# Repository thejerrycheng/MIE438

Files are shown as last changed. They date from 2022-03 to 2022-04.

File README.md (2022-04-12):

# MIE438_LED_cubic_console! 

This is an instruction of how to setup your own 8 by 8 by 8 LED game console. As there are tons of build-videos out there on YouTube. 

This report will only focus on the circuit design and the software aspect on how to light up the cube. Those two aspects were the consierably most challenging parts of the projects. 

In addition, it will walk through the two games created for the cube: Snake and Pong, two most classic console games of all time! (BUT in 3D!)

Lots of embedded system to be discovered. Let's dive into the lowest levels!

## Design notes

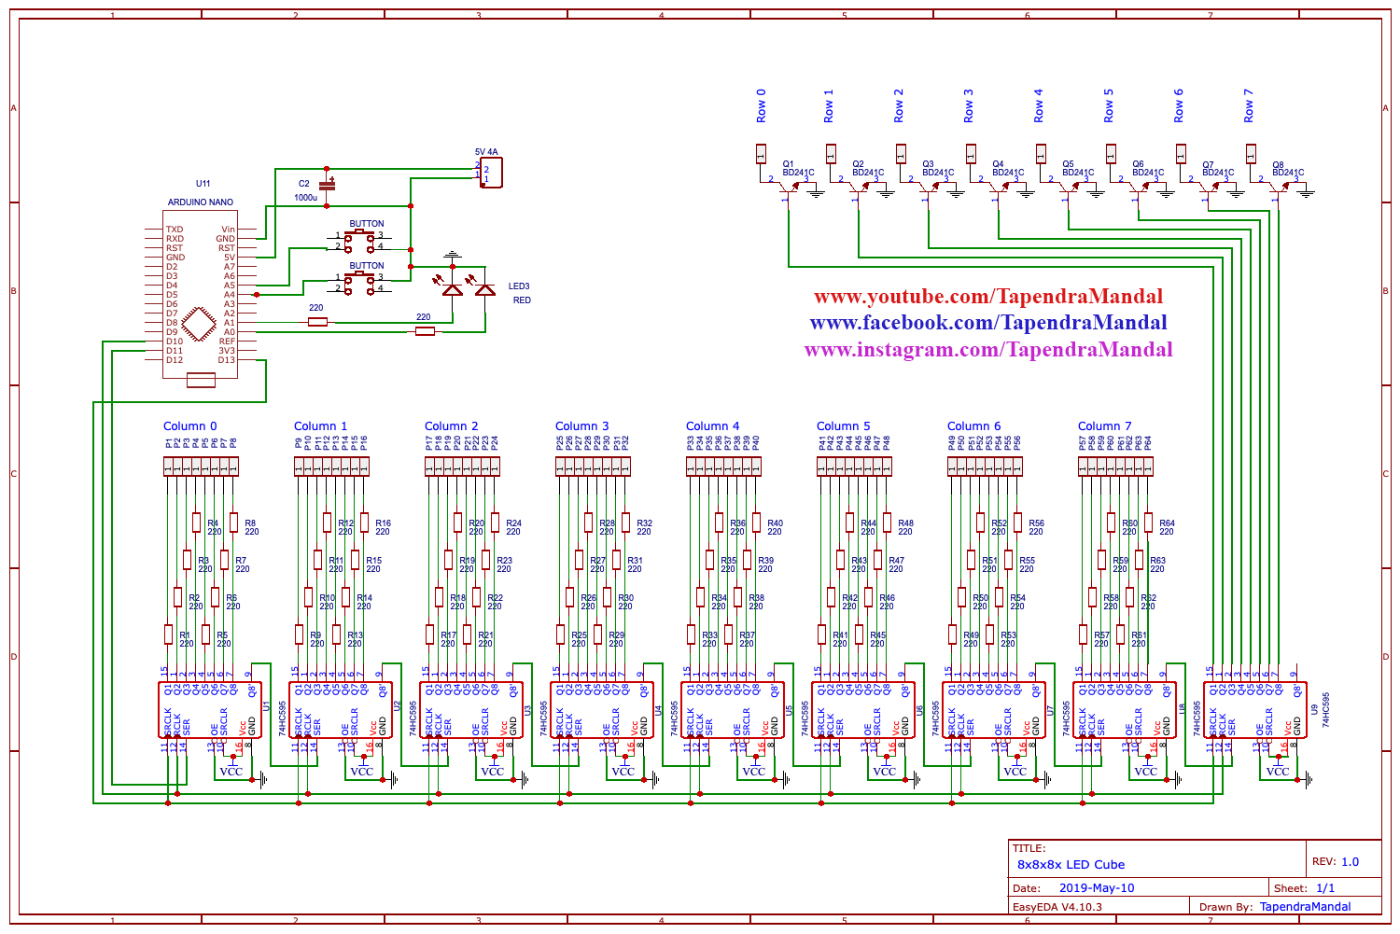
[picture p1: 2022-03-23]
8x8x8 LED Cube Circuit Diagram.jpg

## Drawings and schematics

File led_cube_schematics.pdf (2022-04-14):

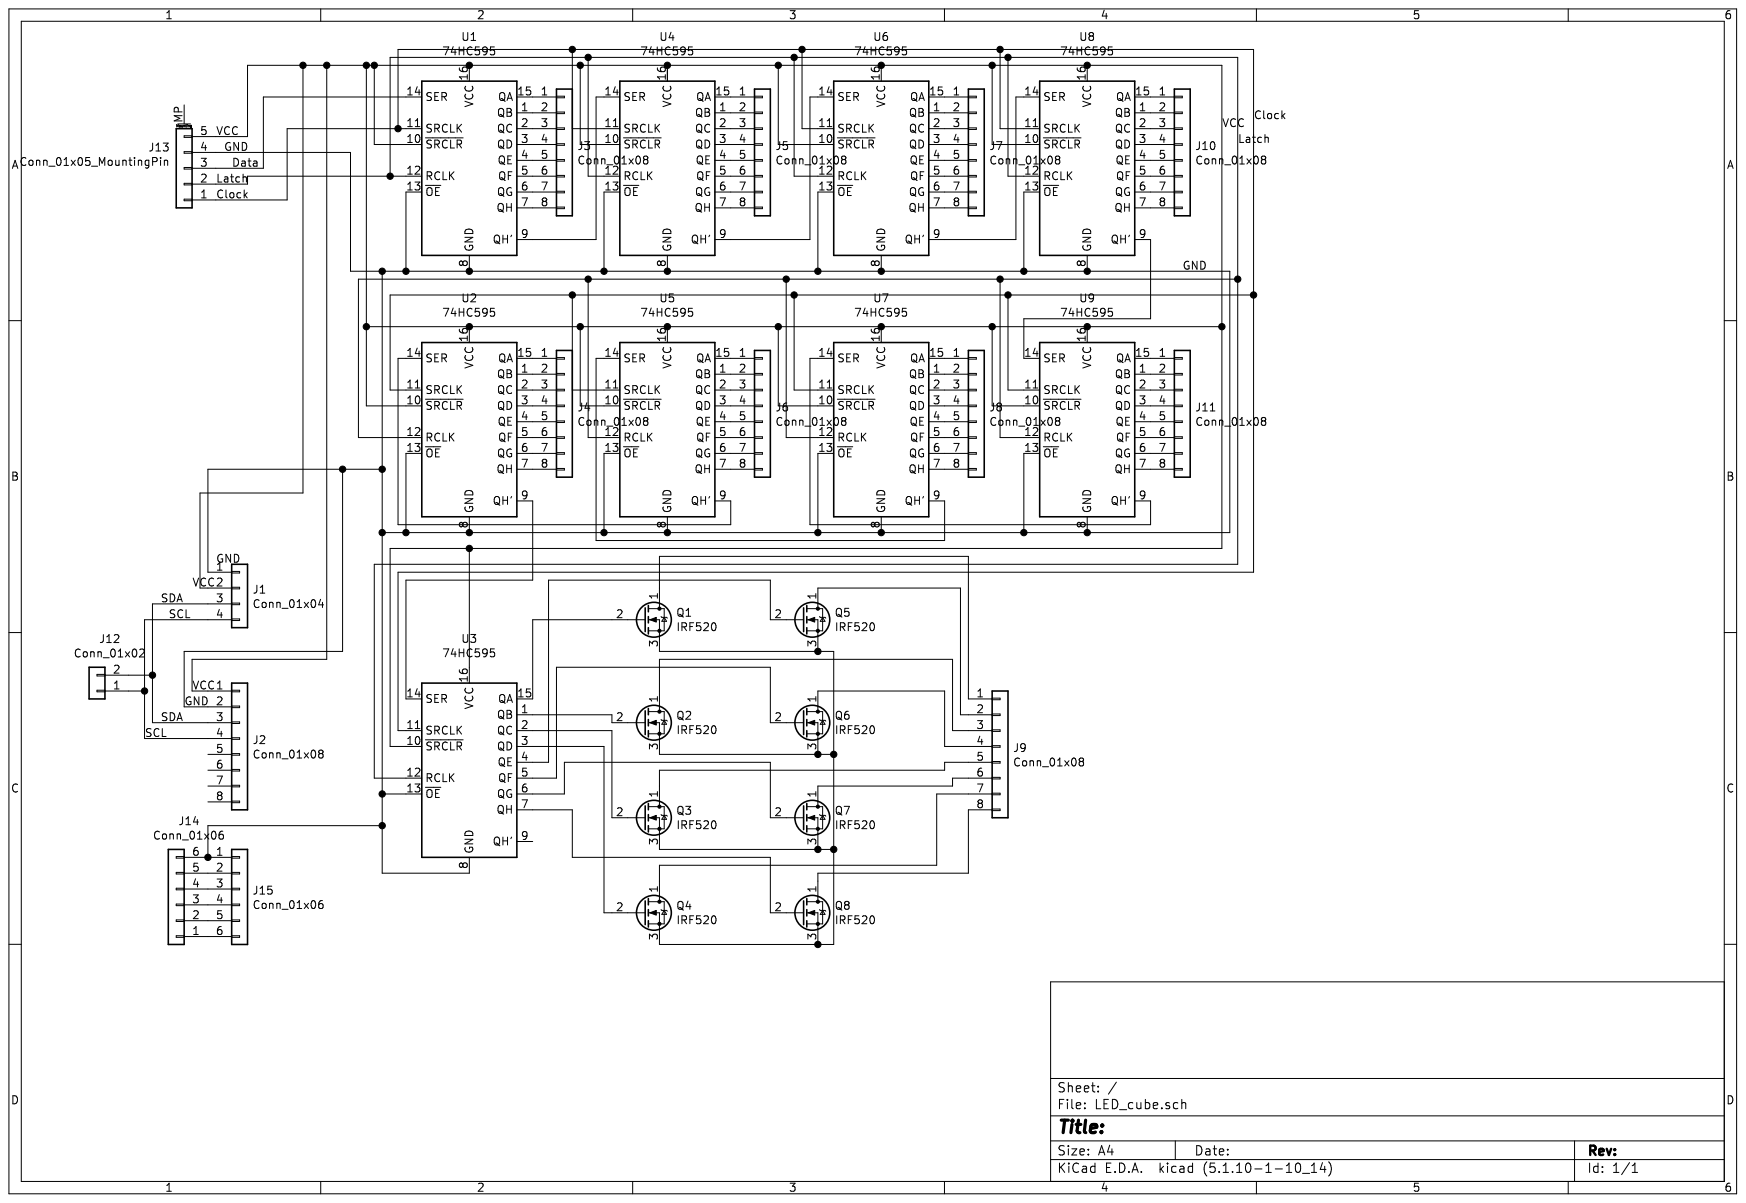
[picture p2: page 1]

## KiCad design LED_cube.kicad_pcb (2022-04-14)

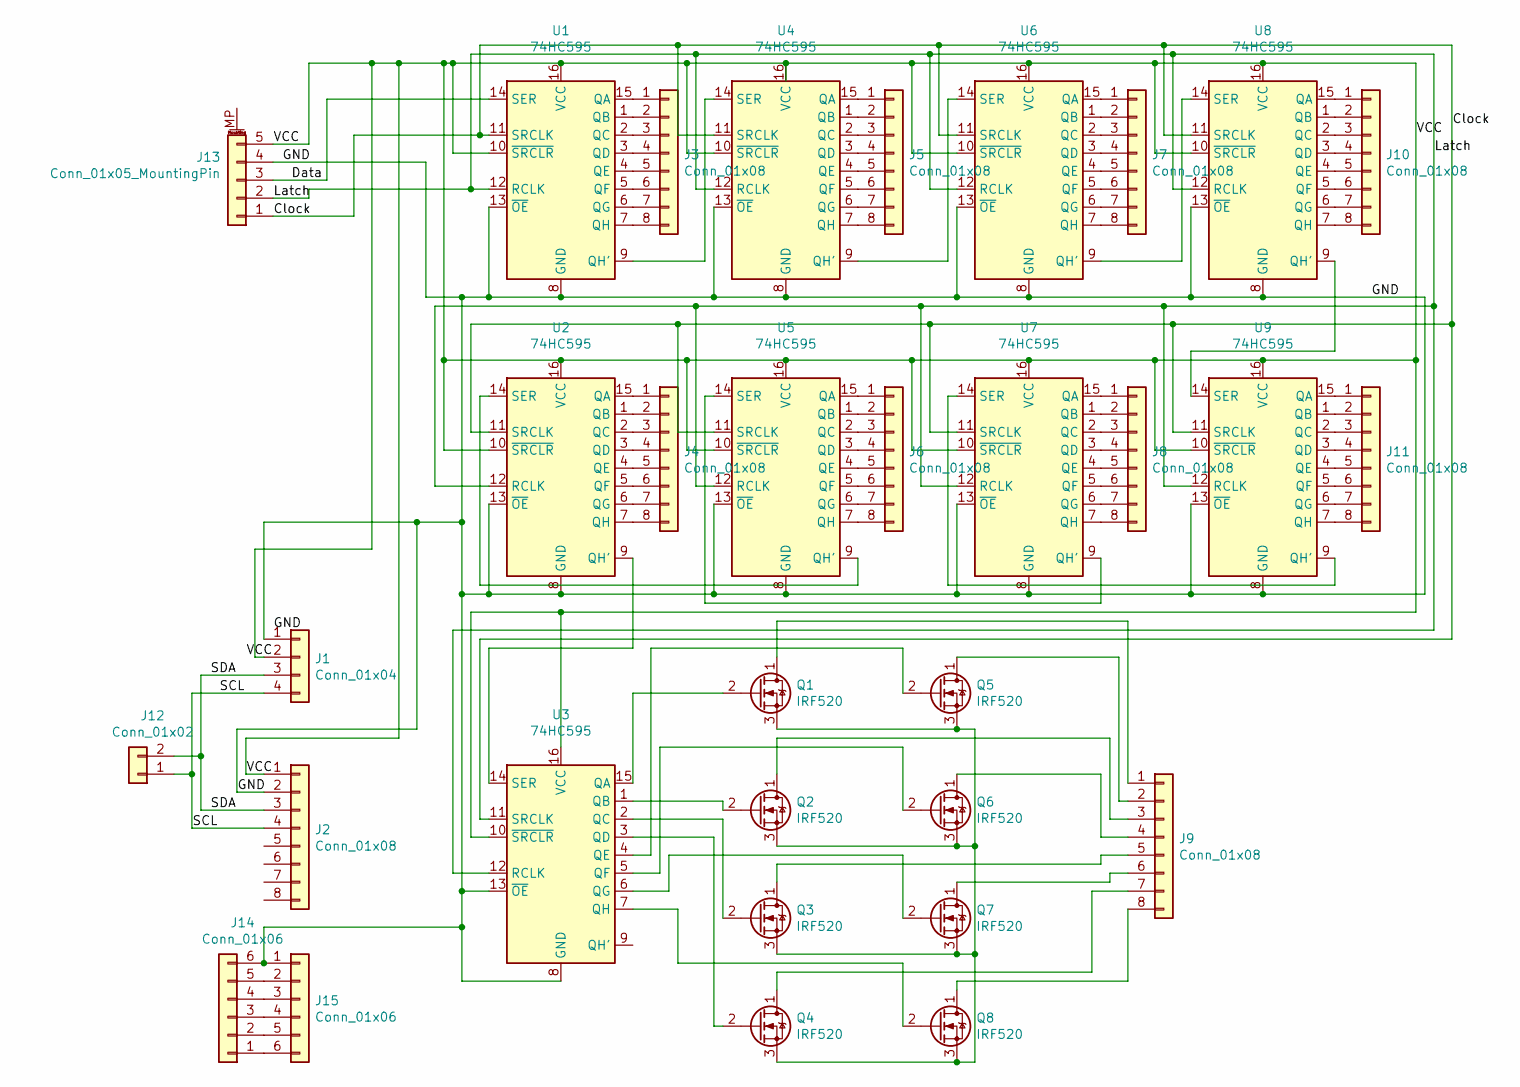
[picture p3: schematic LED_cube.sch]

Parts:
J1: Conn_01x04; PinSocket_1x04_P2.54mm_Vertical
J2, J3, J4, J5, J6, J7, J8, J9, J10, J11: Conn_01x08; PinSocket_1x08_P2.54mm_Vertical
J12: Conn_01x02; PinSocket_1x02_P2.54mm_Vertical
J13: Conn_01x05_MountingPin; PinSocket_1x05_P2.54mm_Vertical
J14, J15: Conn_01x06; PinSocket_1x06_P2.54mm_Vertical
Q1, Q2, Q4, Q7, Q8: IRF520; TO-262-3-1EP_Horizontal_TabDown
Q3: IRF520; DirectFET_MX
Q5, Q6: IRF520; TO-251-3-1EP_Horizontal_TabDown
U1, U2, U3, U4, U5, U6, U7, U8, U9: 74HC595; DIP-16_W7.62mm_Socket

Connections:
/Clock: J13.1, U1.11 (SRCLK), U2.11 (SRCLK), U3.11 (SRCLK), U4.11 (SRCLK), U5.11 (SRCLK), U6.11 (SRCLK), U7.11 (SRCLK), U8.11 (SRCLK), U9.11 (SRCLK)
/Data: J13.3, U1.14 (SER)
/GND: J1.1, J2.2, J13.4, J14.6, J15.1, U1.8 (GND), U1.13 (~OE), U2.8 (GND), U2.13 (~OE), U3.8 (GND), U3.13 (~OE), U4.8 (GND), U4.13 (~OE), U5.8 (GND), U5.13 (~OE), U6.8 (GND), U6.13 (~OE), U7.8 (GND), U7.13 (~OE), U8.8 (GND), U8.13 (~OE), U9.8 (GND), U9.13 (~OE)
/Latch: J13.2, U1.12 (RCLK), U2.12 (RCLK), U3.12 (RCLK), U4.12 (RCLK), U5.12 (RCLK), U6.12 (RCLK), U7.12 (RCLK), U8.12 (RCLK), U9.12 (RCLK)
/SCL: J1.4, J2.4, J12.1
/SDA: J1.3, J2.3, J12.2
/VCC: J1.2, J2.1, J13.5, U1.10 (~SRCLR), U1.16 (VCC), U2.10 (~SRCLR), U2.16 (VCC), U3.10 (~SRCLR), U3.16 (VCC), U4.10 (~SRCLR), U4.16 (VCC), U5.10 (~SRCLR), U5.16 (VCC), U6.10 (~SRCLR), U6.16 (VCC), U7.10 (~SRCLR), U7.16 (VCC), U8.10 (~SRCLR), U8.16 (VCC), U9.10 (~SRCLR), U9.16 (VCC)
unnamed: J3.1, U1.15 (QA)
unnamed: J3.2, U1.1 (QB)
unnamed: J3.3, U1.2 (QC)
unnamed: J3.4, U1.3 (QD)
unnamed: J3.5, U1.4 (QE)
unnamed: J3.6, U1.5 (QF)
unnamed: J3.7, U1.6 (QG)
unnamed: J3.8, U1.7 (QH)
unnamed: J4.1, U2.15 (QA)
unnamed: J4.2, U2.1 (QB)
unnamed: J4.3, U2.2 (QC)
unnamed: J4.4, U2.3 (QD)
unnamed: J4.5, U2.4 (QE)
unnamed: J4.6, U2.5 (QF)
unnamed: J4.7, U2.6 (QG)
unnamed: J4.8, U2.7 (QH)
unnamed: J5.1, U4.15 (QA)
unnamed: J5.2, U4.1 (QB)
unnamed: J5.3, U4.2 (QC)
unnamed: J5.4, U4.3 (QD)
unnamed: J5.5, U4.4 (QE)
unnamed: J5.6, U4.5 (QF)
unnamed: J5.7, U4.6 (QG)
unnamed: J5.8, U4.7 (QH)
unnamed: J6.1, U5.15 (QA)
unnamed: J6.2, U5.1 (QB)
unnamed: J6.3, U5.2 (QC)
unnamed: J6.4, U5.3 (QD)
unnamed: J6.5, U5.4 (QE)
unnamed: J6.6, U5.5 (QF)
unnamed: J6.7, U5.6 (QG)
unnamed: J6.8, U5.7 (QH)
unnamed: J7.1, U6.15 (QA)
unnamed: J7.2, U6.1 (QB)
unnamed: J7.3, U6.2 (QC)
unnamed: J7.4, U6.3 (QD)
unnamed: J7.5, U6.4 (QE)
unnamed: J7.6, U6.5 (QF)
unnamed: J7.7, U6.6 (QG)
unnamed: J7.8, U6.7 (QH)
unnamed: J8.1, U7.15 (QA)
unnamed: J8.2, U7.1 (QB)
unnamed: J8.3, U7.2 (QC)
unnamed: J8.4, U7.3 (QD)
unnamed: J8.5, U7.4 (QE)
unnamed: J8.6, U7.5 (QF)
unnamed: J8.7, U7.6 (QG)
unnamed: J8.8, U7.7 (QH)
unnamed: J9.1, Q1.1 (D)
unnamed: J9.2, Q5.1 (D)
unnamed: J9.3, Q2.1 (D)
unnamed: J9.4, Q6.1 (D)
unnamed: J9.5, Q3.1 (D)
unnamed: J9.6, Q7.1 (D)
unnamed: J9.7, Q4.1 (D)
unnamed: J9.8, Q8.1 (D)
unnamed: J10.1, U8.15 (QA)
unnamed: J10.2, U8.1 (QB)
unnamed: J10.3, U8.2 (QC)
unnamed: J10.4, U8.3 (QD)
unnamed: J10.5, U8.4 (QE)
unnamed: J10.6, U8.5 (QF)
unnamed: J10.7, U8.6 (QG)
unnamed: J10.8, U8.7 (QH)
unnamed: J11.1, U9.15 (QA)
unnamed: J11.2, U9.1 (QB)
unnamed: J11.3, U9.2 (QC)
unnamed: J11.4, U9.3 (QD)
unnamed: J11.5, U9.4 (QE)
unnamed: J11.6, U9.5 (QF)
unnamed: J11.7, U9.6 (QG)
unnamed: J11.8, U9.7 (QH)
unnamed: J14.1, J15.6
unnamed: J14.2, J15.5
unnamed: J14.3, J15.4
unnamed: J14.4, J15.3
unnamed: J14.5, J15.2
unnamed: Q1.2 (G), U3.15 (QA)
unnamed: Q1.3 (S), Q2.3 (S), Q3.3 (S), Q4.3 (S), Q5.3 (S), Q6.3 (S), Q7.3 (S), Q8.3 (S)
unnamed: Q2.2 (G), U3.1 (QB)
unnamed: Q3.2 (G), U3.2 (QC)
unnamed: Q4.2 (G), U3.3 (QD)
unnamed: Q5.2 (G), U3.4 (QE)
unnamed: Q6.2 (G), U3.5 (QF)
unnamed: Q7.2 (G), U3.6 (QG)
unnamed: Q8.2 (G), U3.7 (QH)
unnamed: U1.9 (QH'), U4.14 (SER)
unnamed: U2.9 (QH'), U3.14 (SER)
unnamed: U2.14 (SER), U5.9 (QH')
unnamed: U4.9 (QH'), U6.14 (SER)
unnamed: U5.14 (SER), U7.9 (QH')
unnamed: U6.9 (QH'), U8.14 (SER)
unnamed: U7.14 (SER), U9.9 (QH')
unnamed: U8.9 (QH'), U9.14 (SER)

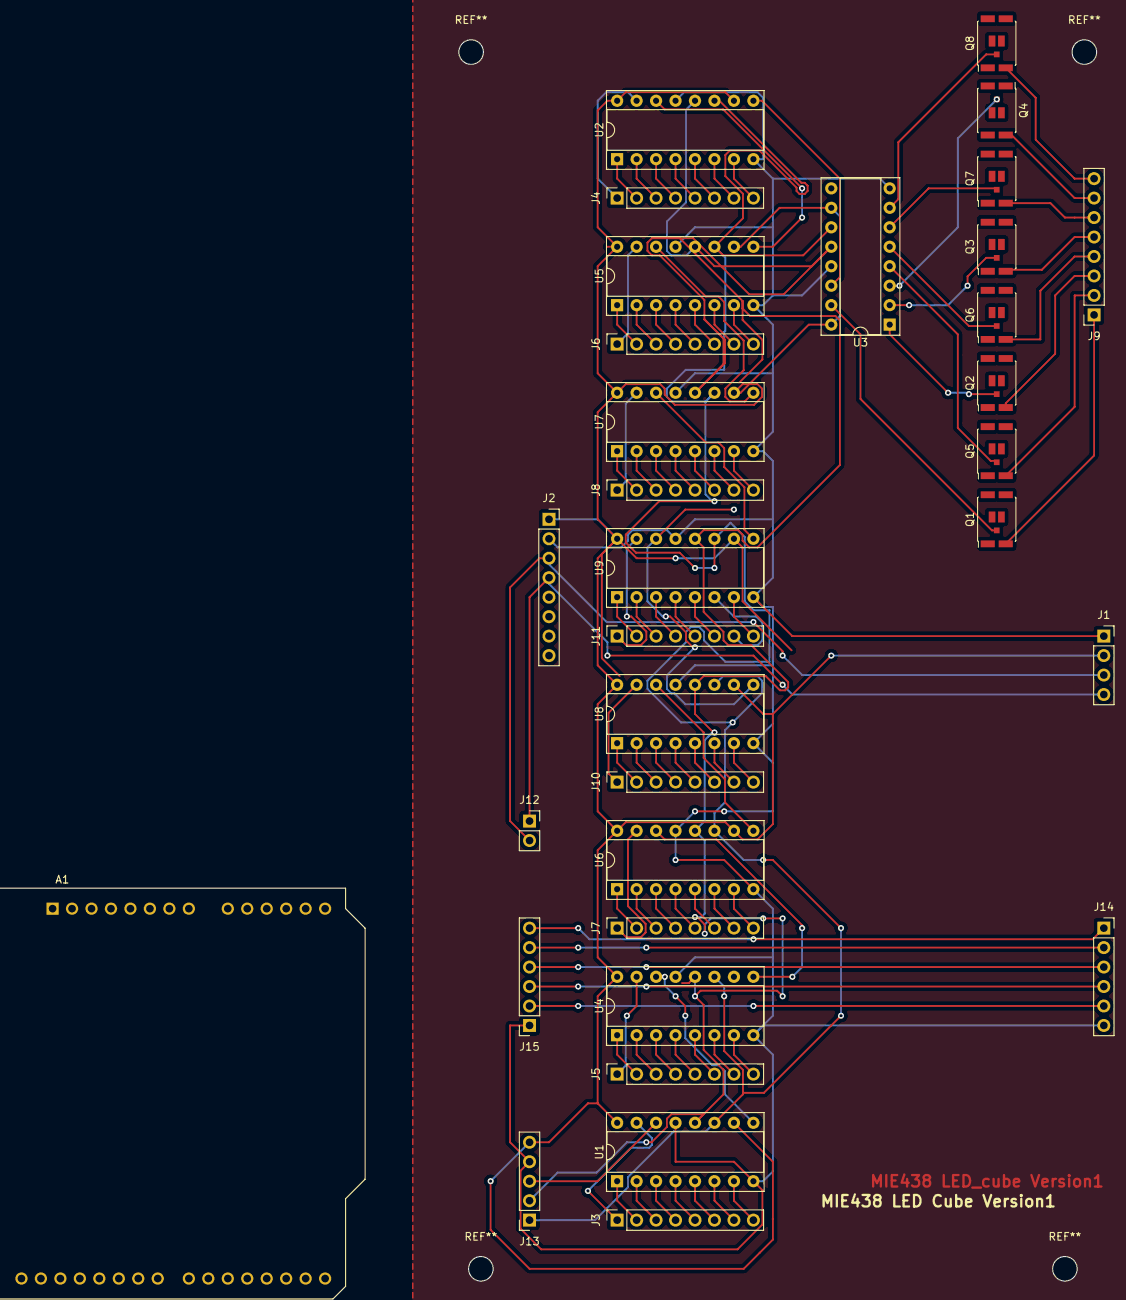
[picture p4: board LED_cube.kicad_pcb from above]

Board: 2 copper layers, 33 parts (0 on the bottom side), 101 nets.

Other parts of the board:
A1: Arduino_UNO_R2

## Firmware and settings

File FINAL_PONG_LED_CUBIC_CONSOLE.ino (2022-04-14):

#include <TimerOne.h>

#include <SPI.h>

#define XAXIS 0
#define YAXIS 1
#define ZAXIS 2

#define POS_X 0
#define NEG_X 1
#define POS_Z 2
#define NEG_Z 3
#define POS_Y 4
#define NEG_Y 5

#define BUTTON_PIN 8
#define RED_LED 5
#define GREEN_LED 7

#define TOTAL_EFFECTS 7
#define RAIN 0
#define PLANE_BOING 1
#define SEND_VOXELS 2
#define WOOP_WOOP 3
#define CUBE_JUMP 4
#define GLOW 5
#define TEXT 6
//#define LIT 7

#define RAIN_TIME 260
#define PLANE_BOING_TIME 220
#define SEND_VOXELS_TIME 140
#define WOOP_WOOP_TIME 350
#define CUBE_JUMP_TIME 200
#define GLOW_TIME 8
#define TEXT_TIME 300
#define CLOCK_TIME 500

uint8_t characters[10][8] = {
  {0x3C, 0x42, 0x42, 0x42, 0x42, 0x42, 0x42, 0x3C}, //0
  {0x10, 0x18, 0x14, 0x10, 0x10, 0x10, 0x10, 0x3C}, //1
  {0x3C, 0x42, 0x40, 0x40, 0x3C, 0x02, 0x02, 0x7E}, //2
  {0x3C, 0x40, 0x40, 0x3C, 0x40, 0x40, 0x42, 0x3C}, //3
  {0x22, 0x22, 0x22, 0x22, 0x7E, 0x20, 0x20, 0x20}, //4
  {0x7E, 0x02, 0x02, 0x3E, 0x40, 0x40, 0x42, 0x3C}, //5
  {0x3C, 0x02, 0x02, 0x3E, 0x42, 0x42, 0x42, 0x3C}, //6
  {0x3C, 0x40, 0x40, 0x40, 0x40, 0x40, 0x40, 0x40}, //7
  {0x3C, 0x42, 0x42, 0x3C, 0x42, 0x42, 0x42, 0x3C}, //8
  {0x3C, 0x42, 0x42, 0x42, 0x3C, 0x40, 0x40, 0x3C}, //9
};

uint8_t cube[8][8];
uint8_t currentEffect;
uint16_t timer;
uint64_t randomTimer;
bool loading;

int slaveSelectPin = 52;

int refresh_time = 0.1;
int layer_time = 0.01;

///////////////////////////////// global function to set the state of a voxel /////////////////////////////////
void writeVoxel(uint8_t x, uint8_t y, uint8_t z, bool state) {
  if (state == 0) {
    clearVoxel(x, y, z);
  }
  else {
    setVoxel(x, y, z);
  }
}

///////////////////////////////// set a voxel /////////////////////////////////
void setVoxel(uint8_t x, uint8_t y, uint8_t z) {
  cube[7 - y][7 - z] |= (0x01 << x);
}
///////////////////////////////// clear a voxel /////////////////////////////////
void clearVoxel(uint8_t x, uint8_t y, uint8_t z) {
  cube[y][z] &= ~(1 << x);
}
///////////////////////////////// flip a voxel /////////////////////////////////
void flipVoxel(uint8_t x, uint8_t y, uint8_t z) {
  cube[7 - y][7 - z] ^= (0x01 << x);
}
///////////////////////////////// get the state of the voxel /////////////////////////////////
bool getVoxel(uint8_t x, uint8_t y, uint8_t z) {
  return (cube[7 - y][7 - z] & (0x01 << x)) == (0x01 << x);
}

///////////////////////////////// set a plane to be lit up/////////////////////////////////
void setPlane(uint8_t axis, uint8_t i) {
  for (uint8_t j = 0; j < 8; j++) {
    for (uint8_t k = 0; k < 8; k++) {
      if (axis == XAXIS) {
        setVoxel(i, j, k);
      } else if (axis == YAXIS) {
        setVoxel(j, i, k);
      } else if (axis == ZAXIS) {
        setVoxel(j, k, i);
      }
    }
  }
}

///////////////////////////////// shift a plane to the direction given; dir can be: POS_X; POS_Y; POS_Z; NEG_X; NEG_Y; NEG_Z /////////////////////////////////
void shift(uint8_t dir) {

  if (dir == POS_X) {
    for (uint8_t y = 0; y < 8; y++) {
      for (uint8_t z = 0; z < 8; z++) {
        cube[y][z] = cube[y][z] << 1;
      }
    }
  } else if (dir == NEG_X) {
    for (uint8_t y = 0; y < 8; y++) {
      for (uint8_t z = 0; z < 8; z++) {
        cube[y][z] = cube[y][z] >> 1;
      }
    }
  } else if (dir == POS_Y) {
    for (uint8_t y = 1; y < 8; y++) {
      for (uint8_t z = 0; z < 8; z++) {
        cube[y - 1][z] = cube[y][z];
      }
    }
    for (uint8_t i = 0; i < 8; i++) {
      cube[7][i] = 0;
    }
  } else if (dir == NEG_Y) {
    for (uint8_t y = 7; y > 0; y--) {
      for (uint8_t z = 0; z < 8; z++) {
        cube[y][z] = cube[y - 1][z];
      }
    }
    for (uint8_t i = 0; i < 8; i++) {
      cube[0][i] = 0;
    }
  } else if (dir == POS_Z) {
    for (uint8_t y = 0; y < 8; y++) {
      for (uint8_t z = 1; z < 8; z++) {
        cube[y][z - 1] = cube[y][z];
      }
    }
    for (uint8_t i = 0; i < 8; i++) {
      cube[i][7] = 0;
    }
  } else if (dir == NEG_Z) {
    for (uint8_t y = 0; y < 8; y++) {
      for (uint8_t z = 7; z > 0; z--) {
        cube[y][z] = cube[y][z - 1];
      }
    }
    for (uint8_t i = 0; i < 8; i++) {
      cube[i][0] = 0;
    }
  }
}

///////////////////////////////// Draw a hallow cube /////////////////////////////////
void drawCube(uint8_t x, uint8_t y, uint8_t z, uint8_t s) {
  for (uint8_t i = 0; i < s; i++) {
    setVoxel(x, y + i, z);
    setVoxel(x + i, y, z);
    setVoxel(x, y, z + i);
    setVoxel(x + s - 1, y + i, z + s - 1);
    setVoxel(x + i, y + s - 1, z + s - 1);
    setVoxel(x + s - 1, y + s - 1, z + i);
    setVoxel(x + s - 1, y + i, z);
    setVoxel(x, y + i, z + s - 1);
    setVoxel(x + i, y + s - 1, z);
    setVoxel(x + i, y, z + s - 1);
    setVoxel(x + s - 1, y, z + i);
    setVoxel(x, y + s - 1, z + i);
  }
}
///////////////////////////////// set the buffer to ON for the entire cube /////////////////////////////////
void lightCube() {
  for (uint8_t i = 0; i < 8; i++) {
    for (uint8_t j = 0; j < 8; j++) {
      cube[i][j] = 0xFF;
    }
  }
}

///////////////////////////////// clear up all the buffer to OFF for enture cube /////////////////////////////////
void clearCube() {
  for (uint8_t i = 0; i < 8; i++) {
    for (uint8_t j = 0; j < 8; j++) {
      cube[i][j] = 0;
    }
  }
}


///////////////////////////////// Send the buffer data to the LED Cube! equvlent to display.display() function from the OLED display  /////////////////////////////////
//void renderCube() {
//  for (uint8_t i = 0; i < 8; i++) {
//    digitalWrite(slaveSelectPin, LOW);
//    SPI.transfer(0x01 << i);
//    //   SPI.transfer(0xFF);
//    for (uint8_t j = 0; j < 8; j++) {
//      SPI.transfer(cube[i][j]);
//      //SPI.transfer(0x11);
//      //delay(layer_time);
//    }
//    digitalWrite(slaveSelectPin, HIGH);
//  }
//  //delay(layer_time * 5);
//  for (uint8_t k = 0; k < 8; k++) {
//    digitalWrite(slaveSelectPin, LOW);
//    SPI.transfer(0x01 << k);
//    //    SPI.transfer(0xFF);
//    for (uint8_t j = 0; j < 8; j++) {
//      //      SPI.transfer(cube[k][j]);
//      SPI.transfer(0x00);
//    }
//    digitalWrite(slaveSelectPin, HIGH);
//  }
//  //delay(refresh_time);
//}



void renderCube() {
  for (uint8_t i = 0; i < 8; i++) {
    digitalWrite(SS, LOW);

    SPI.transfer(0x01 << i);
    for (uint8_t j = 0; j < 8; j++) {
      SPI.transfer(cube[i][j]);
    }
    digitalWrite(SS, HIGH);
  }
}

///////////////////////////////////////////////////////////////////////////
///////////////////////////////// Effects /////////////////////////////////
///////////////////////////////////////////////////////////////////////////


///////////////////////////////// Rain Effects /////////////////////////////////
void rain() {
  if (loading) {
    clearCube();
    loading = false;
  }
  timer++;
  if (timer > RAIN_TIME) {
    timer = 0;
    shift(NEG_Y);
    uint8_t numDrops = random(0, 5);
    for (uint8_t i = 0; i < numDrops; i++) {
      setVoxel(random(0, 8), 7, random(0, 8));
    }
  }
}
///////////////////////////////// Plane Boing Effects /////////////////////////////////

uint8_t planePosition = 0;
uint8_t planeDirection = 0;
bool looped = false;


void planeBoing() {
  if (loading) {
    clearCube();
    uint8_t axis = random(0, 3);
    planePosition = random(0, 2) * 7;
    setPlane(axis, planePosition);
    if (axis == XAXIS) {
      if (planePosition == 0) {
        planeDirection = POS_X;
      } else {
        planeDirection = NEG_X;
      }
    } else if (axis == YAXIS) {
      if (planePosition == 0) {
        planeDirection = POS_Y;
      } else {
        planeDirection = NEG_Y;
      }
    } else if (axis == ZAXIS) {
      if (planePosition == 0) {
        planeDirection = POS_Z;
      } else {
        planeDirection = NEG_Z;
      }
    }
    timer = 0;
    looped = false;
    loading = false;
  }

  timer++;
  if (timer > PLANE_BOING_TIME) {
    timer = 0;
    shift(planeDirection);
    if (planeDirection % 2 == 0) {
      planePosition++;
      if (planePosition == 7) {
        if (looped) {
          loading = true;
        } else {
          planeDirection++;
          looped = true;
        }
      }
    } else {
      planePosition--;
      if (planePosition == 0) {
        if (looped) {
          loading = true;
        } else {
          planeDirection--;
          looped = true;
        }
      }
    }
  }
}


///////////////////////////////// Send Voxel Effects /////////////////////////////////
uint8_t selX = 0;
uint8_t selY = 0;
uint8_t selZ = 0;
uint8_t sendDirection = 0;
bool sending = false;

void sendVoxels() {
  if (loading) {
    clearCube();
    for (uint8_t x = 0; x < 8; x++) {
      for (uint8_t z = 0; z < 8; z++) {
        setVoxel(x, random(0, 2) * 7, z);
      }
    }
    loading = false;
  }

  timer++;
  if (timer > SEND_VOXELS_TIME) {
    timer = 0;
    if (!sending) {
      selX = random(0, 8);
      selZ = random(0, 8);
      if (getVoxel(selX, 0, selZ)) {
        selY = 0;
        sendDirection = POS_Y;
      } else if (getVoxel(selX, 7, selZ)) {
        selY = 7;
        sendDirection = NEG_Y;
      }
      sending = true;
    } else {
      if (sendDirection == POS_Y) {
        selY++;
        setVoxel(selX, selY, selZ);
        clearVoxel(selX, selY - 1, selZ);
        if (selY == 7) {
          sending = false;
        }
      } else {
        selY--;
        setVoxel(selX, selY, selZ);
        clearVoxel(selX, selY + 1, selZ);
        if (selY == 0) {
          sending = false;
        }
      }
    }
  }
}




///////////////////////////////// Woop woop Effects /////////////////////////////////
uint8_t cubeSize = 0;
bool cubeExpanding = true;

void woopWoop() {
  if (loading) {
    clearCube();
    cubeSize = 2;
    cubeExpanding = true;
    loading = false;
  }

  timer++;
  if (timer > WOOP_WOOP_TIME) {
    timer = 0;
    if (cubeExpanding) {
      cubeSize += 2;
      if (cubeSize == 8) {
        cubeExpanding = false;
      }
    } else {
      cubeSize -= 2;
      if (cubeSize == 2) {
        cubeExpanding = true;
      }
    }
    clearCube();
    drawCube(4 - cubeSize / 2, 4 - cubeSize / 2, 4 - cubeSize / 2, cubeSize);
  }
}

///////////////////////////////// Cube Jump Effects /////////////////////////////////

uint8_t xPos;
uint8_t yPos;
uint8_t zPos;

void cubeJump() {
  if (loading) {
    clearCube();
    xPos = random(0, 2) * 7;
    yPos = random(0, 2) * 7;
    zPos = random(0, 2) * 7;
    cubeSize = 8;
    cubeExpanding = false;
    loading = false;
  }

  timer++;
  if (timer > CUBE_JUMP_TIME) {
    timer = 0;
    clearCube();
    if (xPos == 0 && yPos == 0 && zPos == 0) {
      drawCube(xPos, yPos, zPos, cubeSize);
    } else if (xPos == 7 && yPos == 7 && zPos == 7) {
      drawCube(xPos + 1 - cubeSize, yPos + 1 - cubeSize, zPos + 1 - cubeSize, cubeSize);
    } else if (xPos == 7 && yPos == 0 && zPos == 0) {
      drawCube(xPos + 1 - cubeSize, yPos, zPos, cubeSize);
    } else if (xPos == 0 && yPos == 7 && zPos == 0) {
      drawCube(xPos, yPos + 1 - cubeSize, zPos, cubeSize);
    } else if (xPos == 0 && yPos == 0 && zPos == 7) {
      drawCube(xPos, yPos, zPos + 1 - cubeSize, cubeSize);
    } else if (xPos == 7 && yPos == 7 && zPos == 0) {
      drawCube(xPos + 1 - cubeSize, yPos + 1 - cubeSize, zPos, cubeSize);
    } else if (xPos == 0 && yPos == 7 && zPos == 7) {
      drawCube(xPos, yPos + 1 - cubeSize, zPos + 1 - cubeSize, cubeSize);
    } else if (xPos == 7 && yPos == 0 && zPos == 7) {
      drawCube(xPos + 1 - cubeSize, yPos, zPos + 1 - cubeSize, cubeSize);
    }
    if (cubeExpanding) {
      cubeSize++;
      if (cubeSize == 8) {
        cubeExpanding = false;
        xPos = random(0, 2) * 7;
        yPos = random(0, 2) * 7;
        zPos = random(0, 2) * 7;
      }
    } else {
      cubeSize--;
      if (cubeSize == 1) {
        cubeExpanding = true;
      }
    }
  }
}


///////////////////////////////// Glowing Effects /////////////////////////////////

bool glowing;
uint16_t glowCount = 0;

void glow() {
  if (loading) {
    clearCube();
    glowCount = 0;
    glowing = true;
    loading = false;
  }

  timer++;
  if (timer > GLOW_TIME) {
    timer = 0;
    if (glowing) {
      if (glowCount < 448) {
        do {
          selX = random(0, 8);
          selY = random(0, 8);
          selZ = random(0, 8);
        } while (getVoxel(selX, selY, selZ));
        setVoxel(selX, selY, selZ);
        glowCount++;
      } else if (glowCount < 512) {
        lightCube();
        glowCount++;
      } else {
        glowing = false;
        glowCount = 0;
      }
    } else {
      if (glowCount < 448) {
        do {
          selX = random(0, 8);
          selY = random(0, 8);
          selZ = random(0, 8);
        } while (!getVoxel(selX, selY, selZ));
        clearVoxel(selX, selY, selZ);
        glowCount++;
      } else {
        clearCube();
        glowing = true;
        glowCount = 0;
      }
    }
  }
}


///////////////////////////////// Display Numbers from 0-9 Effects /////////////////////////////////

uint8_t charCounter = 0;
uint8_t charPosition = 0;

void text(char string[], uint8_t len) {
  if (loading) {
    clearCube();
    charPosition = -1;
    charCounter = 0;
    loading = false;
  }


  shift(NEG_Z);
  charPosition++;

  if (charPosition == 7) {
    charCounter++;
    if (charCounter > len - 1) {
      charCounter = 0;
    }
    charPosition = 0;
  }

  if (charPosition == 0) {
    for (uint8_t i = 0; i < 8; i++) {
      cube[i][0] = characters[string[charCounter] - '0'][i];
    }
  }

}

///////////////////////////////// Lit up Effects /////////////////////////////////

void lit() {
  if (loading) {
    clearCube();
    for (uint8_t i = 0; i < 8; i++) {
      for (uint8_t j = 0; j < 8; j++) {
        cube[i][j] = 0xFF;
      }
    }
    loading = false;
  }
}




///////////////////////////////// Automatically Rendered Effects //////////////////////////////////

void effect_text() {

  for (int i = 0; i < 20000; i++) {
    text("0123456789", 10);
    renderCube();

  }
  //  clearCube();
  //  renderCube();
  currentEffect ++;

}

void effect_planeBoing() {

  for (int i = 0; i < 20000; i++) {
    planeBoing();
    renderCube();

  }
  clearCube();
  renderCube();
  currentEffect ++;

}

void effect_rain() {

  for (int i = 0; i < 20000; i++) {
    rain();
    renderCube();

  }
  clearCube();
  renderCube();
  currentEffect ++;

}


void effect_sendVoxels() {

  for (int i = 0; i < 20000; i++) {
    sendVoxels();
    renderCube();

  }
  clearCube();
  renderCube();
  currentEffect ++;

}

void effect_cubeJump() {

  for (int i = 0; i < 20000; i++) {
    cubeJump();
    renderCube();

  }
  clearCube();
  renderCube();
  currentEffect ++;

}

void effect_woopWoop() {

  for (int i = 0; i < 20000; i++) {
    cubeJump();
    renderCube();

  }
  woopWoop();
  renderCube();
  currentEffect ++;

}

void effect_glow() {

  for (int i = 0; i < 20000; i++) {
    glow();
    renderCube();

  }
  woopWoop();
  renderCube();
  currentEffect ++;

}




///////////////////////// setup /////////////////////////////////

const int poX = A1;
const int poY = A2;
const int poZ = A3;
const int poI = A4;
const int poPress = 7;
const int posZ = A3;
const int posI = A4;

/////////////////////////////////Effect Animation Showcase: /////////////////////////////////

void start_animation() {
  for (int i = 0; i < 20000; i++) {
    rain();
    renderCube();

  }
  clearCube();
  //renderCube();

  for (int i = 0; i < 20000; i++) {
    planeBoing();
    // renderCube();

  }
  clearCube();
  renderCube();
  ///////////////////////////////// /////////////////////////////////
  for (int i = 0; i < 20000; i++) {
    woopWoop();
    renderCube();

  }
  clearCube();
  renderCube();
  ///////////////////////////////// /////////////////////////////////

  ///////////////////////////////// /////////////////////////////////
  for (int i = 0; i < 20000; i++) {
    cubeJump();
    renderCube();

  }
  clearCube();
  renderCube();

}




////////////////////////////////////////////////////
/////////////PONG GAME SETUP //////////////////////
////////////////////////////////////////////////////



///////////////////////////////// PONG GAME /////////////////////////////////
//
//
//class cBall {
//  private:
//    int ballX, ballY, ballZ;
//    int originalX, originalY, originalZ;
//    eDir direction;
//
//  public:
//    cBall(int posX, int posY, int posZ) {
//      originalX = posX;
//      originalY = posY;
//      originalZ = posZ;
//      ballX = posX;
//      ballY = posY;
//      ballZ = posZ;
//      direction = pSTOP;
//    }
//
//    void Reset() {
//      ballX = originalX;
//      ballY = originalY;
//      ballZ = originalZ;
//      direction = pSTOP;
//    }
//
//    void changeDirection(eDir d) {
//      direction = d;
//    }
//
//    inline int getX() {
//      return ballX;
//    }
//
//    inline int getY() {
//      return ballY;
//    }
//
//    inline int getZ() {
//      return ballZ;
//    }
//
//    inline eDir getDirection() {
//      return direction;
//    }
//    void randomDirection() {
//      direction = (eDir)(random(1, 11)); // randomly select a direction to move to from 1-10
//    }
//
//    void Move() {
//      switch (direction) {
//        case pSTOP:
//          break;
//
//        case pUP:
//          ballZ ++;
//          break;
//
//        case pUPLEFT:
//          ballZ ++;
//          ballX --;
//          break;
//
//        case pUPRIGHT:
//          ballZ ++;
//          ballX ++;
//          break;
//
//
//        case pUPIN:
//          ballZ ++;
//          ballY ++;
//          break;
//
//        case pUPOUT:
//          ballZ ++;
//          ballY --;
//          break;
//
//        case pDOWN:
//          ballZ --;
//          break;
//
//        case pDOWNLEFT:
//          ballZ --;
//          ballX --;
//          break;
//
//        case pDOWNRIGHT:
//          ballZ --;
//          ballX ++;
//          break;
//
//        case pDOWNIN:
//          ballZ --;
//          ballY ++;
//          break;
//
//        case pDOWNOUT:
//          ballZ --;
//          ballY --;
//          break;
//
//        default:
//          break;
//      }
//    }
//
//};
//
//class cPaddle {
//  private:
//    int x, y, z;
//    int originalX, originalY, originalZ;
//
//  public:
//    cPaddle() {
//      x = y = z = 0;
//    }
//
//    cPaddle(int posX, int posY, int posZ) {
//      originalX = posX;
//      originalY = posY;
//      originalZ = posZ;
//      x = posX;
//      y = posY;
//      z = posZ;
//    }
//
//    inline void Reset() {
//      x = originalX;
//      y = originalY;
//      z = originalZ;
//    }
//
//    inline void getX() {
//      return x;
//    }
//
//    inline void getY() {
//      return y;
//    }
//
//    inline void getZ() {
//      return z;
//    }
//
//    inline void moveForward() {
//      y++;
//    }
//
//    inline void moveBackward() {
//      y--;
//    }
//
//    inline void moveLeft() {
//      x++;
//    }
//
//    inline void moveRight() {
//      x--;
//    }
//};
//
//class cGameManager {
//  private:
//    int width = 7;
//    int height = 7;
//    int depth = 7;
//    int score1, score2;
//    char forward1, backward1, left1, right1, forward2, backward2, left2, right2;
//    bool quit;
//    cBall*ball;
//    cPaddle *player1;
//    cPaddle *player2;
//
//  public:
//    cGameManager() {
//      quit = false;
//      //      if () {
//      //
//      //      }
//      //      else if () {
//      //
//      //      }
//      //      else if () {
//      //
//      //      }
//      //      else if () {
//      //
//      //      }
//      //
//      //
//      //      if () {
//      //
//      //      }
//      //      else if () {
//      //
//      //      }
//      //      else if () {
//      //
//      //      }
//      //      else if () {
//      //
//      //      }
//
//      score1 = score2 = 0;
//      ball = new cBall(4, 4, 4);
//      player1 = new cPaddle(4, 4, 0);
//      player2 = new cPaddle(4, 4, 7);
//    }
//
//    ~cGameManager() {
//      delete ball, player1, player2;
//    }
//
//    void ScoreUp(cPaddle *player) {
//      if (player == player1) {
//        score1++;
//      }
//      else if (player == player2) {
//        score2++;
//      }
//
//      ball -> Reset();
//      player1 -> Reset();
//      player2 -> Reset();
//    }
//
//
//    void Draw() {
//
//    }
//
//};





int score = 0;
bool gameOver = false;
int ballX, ballY, ballZ;
int player1X, player1Y, player1Z;
int player2X, player2Y, player2Z;


int ballInitX = 4;
int ballInitY = 4;
int ballInitZ = 4;

int player1InitX = 4;
int player1InitY = 4;
int player1InitZ = 0;

int player2InitX = 4;
int player2InitY = 4;
int player2InitZ = 7;

enum ePLAYER {
  LEFT1 = 0,
  RIGHT1 = 1,
  UP1 = 2,
  DOWN1 = 3,
  STOP1 = 4,

  LEFT2 = 5,
  RIGHT2 = 6,
  UP2 = 7,
  DOWN2 = 8,
  STOP2 = 9
};

enum eBall { // 1 stop state and 10 additional possible directions (5 on each side)
  pSTOP = 0,
  
  pUP = 1,
  pUPLEFT = 2,
  pUPRIGHT = 3,
  pUPIN = 4,
  pUPOUT = 5,
  
  pDOWN = 6,
  pDOWNLEFT = 7,
  pDOWNRIGHT = 8,
  pDOWNIN = 9,
  pDOWNOUT = 10
};

ePLAYER player1Dir;
ePLAYER player2Dir;
eBall ballDir;
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
void loop() {
  //  readInputs();
  int initTime, currentTime;
  int delay_time = 100;

  initTime = millis();

  bool gameOver = false;
  while (!gameOver) {
    Input();


    currentTime = millis();
    if (currentTime - initTime > refrsh_time) {
      Logic();
      Draw();
      initTime = millis();
    }

    //Serial.println("Refreshes just now");
  }
}

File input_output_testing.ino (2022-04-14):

#include <TimerOne.h>

#include <PS2X_lib.h>
#include <SPI.h>
#include <Wire.h>
#include <Adafruit_GFX.h>
#include <Adafruit_SSD1306.h>


//right now, the library does NOT support hot-pluggable controllers, meaning
//you must always either restart your Arduino after you connect the controller,
//or call config_gamepad(pins) again after connecting the controller.

int error = 0;
byte type = 0;
byte vibrate = 0;


#define SCREEN_WIDTH 128 // OLED display width, in pixels
#define SCREEN_HEIGHT 64 // OLED display height, in pixels

// Declaration for an SSD1306 display connected to I2C (SDA, SCL pins)
// The pins for I2C are defined by the Wire-library.
// On an arduino UNO:       A4(SDA), A5(SCL)
// On an arduino MEGA 2560: 20(SDA), 21(SCL)
// On an arduino LEONARDO:   2(SDA),  3(SCL), ...


#define OLED_RESET     4 // Reset pin # (or -1 if sharing Arduino reset pin)
#define SCREEN_ADDRESS 0x3C ///< See datasheet for Address; 0x3D for 128x64, 0x3C for 128x32

Adafruit_SSD1306 display(SCREEN_WIDTH, SCREEN_HEIGHT, &Wire, OLED_RESET);

PS2X ps2x;

enum SNAKE_DIR {
  UP,
  DOWN,
  LEFT,
  RIGHT,
  FORWARD,
  BACKWARD,
};

SNAKE_DIR snake_dir;

const unsigned char PROGMEM frame0 [] = {0x00, 0x00, 0x00, 0x00, 0x00, 0x00, 0x00, 0x00, 0x00, 0x00, 0x00, 0x00, 0x00, 0x00, 0x00, 0x00, 0x00, 0x00, 0x00, 0x00, 0x00, 0x00, 0x00, 0x00, 0x00, 0x00, 0x00, 0x00, 0x00, 0x00, 0x00, 0x00, 0x00, 0x00, 0x00, 0x00, 0x00, 0x00, 0x00, 0x00, 0x00, 0x00, 0x00, 0x00, 0x00, 0x00, 0x00, 0x00, 0x00, 0x30, 0x1F, 0xF8, 0x00, 0x00, 0x00, 0x70, 0x7F, 0xFE, 0x00, 0x00, 0x00, 0x71, 0xFF, 0xFF, 0x80, 0x00, 0x00, 0x73, 0xF0, 0x0F, 0xC0, 0x00, 0x00, 0x7F, 0xC0, 0x03, 0xF0, 0x00, 0x00, 0x7F, 0x00, 0x00, 0xF0, 0x00, 0x00, 0x7E, 0x00, 0x00, 0x78, 0x00, 0x00, 0x7F, 0xE0, 0x00, 0x3C, 0x00, 0x00, 0x7F, 0xE0, 0x00, 0x1C, 0x00, 0x00, 0x3F, 0xE0, 0x00, 0x1E, 0x00, 0x00, 0x00, 0x00, 0x00, 0x0E, 0x00, 0x00, 0x00, 0x00, 0x00, 0x0F, 0x00, 0x00, 0x00, 0x00, 0x00, 0x07, 0x00, 0x00, 0x00, 0x00, 0x00, 0x07, 0x00, 0x00, 0x00, 0x00, 0x00, 0x07, 0x00, 0x00, 0x00, 0x00, 0x00, 0x07, 0x00, 0x00, 0xE0, 0x00, 0x00, 0x00, 0x00, 0x00, 0xE0, 0x00, 0x00, 0x00, 0x00, 0x00, 0xE0, 0x00, 0x00, 0x00, 0x00, 0x00, 0xF0, 0x00, 0x00, 0x00, 0x00, 0x00, 0x70, 0x00, 0x00, 0x00, 0x00, 0x00, 0x70, 0x00, 0x00, 0x00, 0x00, 0x00, 0x78, 0x00, 0x07, 0xFC, 0x00, 0x00, 0x3C, 0x00, 0x07, 0xFE, 0x00, 0x00, 0x3C, 0x00, 0x07, 0xFE, 0x00, 0x00, 0x1E, 0x00, 0x00, 0x7E, 0x00, 0x00, 0x0F, 0x80, 0x01, 0xFE, 0x00, 0x00, 0x07, 0xC0, 0x03, 0xFE, 0x00, 0x00, 0x03, 0xFC, 0x1F, 0xCE, 0x00, 0x00, 0x00, 0xFF, 0xFF, 0x0E, 0x00, 0x00, 0x00, 0x7F, 0xFE, 0x0E, 0x00, 0x00, 0x00, 0x0F, 0xE0, 0x0C, 0x00, 0x00, 0x00, 0x00, 0x00, 0x00, 0x00, 0x00, 0x00, 0x00, 0x00, 0x00, 0x00, 0x00, 0x00, 0x00, 0x00, 0x00, 0x00, 0x00, 0x00, 0x00, 0x00, 0x00, 0x00, 0x00, 0x00, 0x00, 0x00, 0x00, 0x00, 0x00, 0x00, 0x00, 0x00, 0x00, 0x00, 0x00, 0x00, 0x00, 0x00, 0x00, 0x00, 0x00, 0x00, 0x00, 0x00, 0x00, 0x00};

const unsigned char PROGMEM frame1 [] = {0x00, 0x00, 0x00, 0x00, 0x00, 0x00, 0x00, 0x00, 0x00, 0x00, 0x00, 0x00, 0x00, 0x00, 0x00, 0x00, 0x00, 0x00, 0x00, 0x00, 0x00, 0x00, 0x00, 0x00, 0x00, 0x00, 0x00, 0x00, 0x00, 0x00, 0x00, 0x00, 0x00, 0x00, 0x00, 0x00, 0x00, 0x00, 0x00, 0x00, 0x00, 0x00, 0x00, 0x00, 0x00, 0x00, 0x00, 0x00, 0x00, 0x30, 0x1F, 0xF8, 0x00, 0x00, 0x00, 0x70, 0x7F, 0xFE, 0x00, 0x00, 0x00, 0x71, 0xFF, 0xFF, 0x80, 0x00, 0x00, 0x73, 0xF0, 0x0F, 0xC0, 0x00, 0x00, 0x7F, 0xC0, 0x03, 0xF0, 0x00, 0x00, 0x7F, 0x00, 0x00, 0xF0, 0x00, 0x00, 0x7E, 0x00, 0x00, 0x78, 0x00, 0x00, 0x7F, 0xE0, 0x00, 0x3C, 0x00, 0x00, 0x7F, 0xE0, 0x00, 0x1C, 0x00, 0x00, 0x3F, 0xE0, 0x00, 0x1E, 0x00, 0x00, 0x00, 0x00, 0x00, 0x0E, 0x00, 0x00, 0x00, 0x00, 0x00, 0x0F, 0x00, 0x00, 0x00, 0x00, 0x00, 0x07, 0x00, 0x00, 0x00, 0x00, 0x00, 0x07, 0x00, 0x00, 0x00, 0x00, 0x00, 0x07, 0x00, 0x00, 0x00, 0x00, 0x00, 0x07, 0x00, 0x00, 0xE0, 0x00, 0x00, 0x00, 0x00, 0x00, 0xE0, 0x00, 0x00, 0x00, 0x00, 0x00, 0xE0, 0x00, 0x00, 0x00, 0x00, 0x00, 0xF0, 0x00, 0x00, 0x00, 0x00, 0x00, 0x70, 0x00, 0x00, 0x00, 0x00, 0x00, 0x70, 0x00, 0x00, 0x00, 0x00, 0x00, 0x78, 0x00, 0x07, 0xFC, 0x00, 0x00, 0x3C, 0x00, 0x07, 0xFE, 0x00, 0x00, 0x3C, 0x00, 0x07, 0xFE, 0x00, 0x00, 0x1E, 0x00, 0x00, 0x7E, 0x00, 0x00, 0x0F, 0x80, 0x01, 0xFE, 0x00, 0x00, 0x07, 0xC0, 0x03, 0xFE, 0x00, 0x00, 0x03, 0xFC, 0x1F, 0xCE, 0x00, 0x00, 0x00, 0xFF, 0xFF, 0x8E, 0x00, 0x00, 0x00, 0x7F, 0xFE, 0x0E, 0x00, 0x00, 0x00, 0x0F, 0xE0, 0x0C, 0x00, 0x00, 0x00, 0x00, 0x00, 0x00, 0x00, 0x00, 0x00, 0x00, 0x00, 0x00, 0x00, 0x00, 0x00, 0x00, 0x00, 0x00, 0x00, 0x00, 0x00, 0x00, 0x00, 0x00, 0x00, 0x00, 0x00, 0x00, 0x00, 0x00, 0x00, 0x00, 0x00, 0x00, 0x00, 0x00, 0x00, 0x00, 0x00, 0x00, 0x00, 0x00, 0x00, 0x00, 0x00, 0x00, 0x00, 0x00, 0x00};

const unsigned char PROGMEM frame2 [] = {0x00, 0x00, 0x00, 0x00, 0x00, 0x00, 0x00, 0x00, 0x00, 0x00, 0x00, 0x00, 0x00, 0x00, 0x00, 0x00, 0x00, 0x00, 0x00, 0x00, 0x00, 0x00, 0x00, 0x00, 0x00, 0x00, 0x00, 0x00, 0x00, 0x00, 0x00, 0x00, 0x00, 0x03, 0xC0, 0x00, 0x00, 0x00, 0x00, 0x0F, 0xC0, 0x00, 0x00, 0x00, 0x00, 0x7F, 0x80, 0x00, 0x00, 0x00, 0x00, 0xFE, 0x00, 0x00, 0x00, 0x00, 0x00, 0xFE, 0x00, 0x00, 0x00, 0x01, 0xE0, 0x7F, 0x80, 0x00, 0x00, 0x03, 0xE0, 0x7F, 0xC0, 0x00, 0x00, 0x07, 0xC0, 0x3B, 0xE0, 0x00, 0x00, 0x0F, 0x00, 0x3C, 0xF0, 0x00, 0x00, 0x1E, 0x00, 0x3C, 0x78, 0x00, 0x00, 0x3C, 0x00, 0x1C, 0x3C, 0x00, 0x00, 0x38, 0x00, 0x08, 0x1C, 0x00, 0x00, 0x78, 0x00, 0x00, 0x1E, 0x00, 0x00, 0x70, 0x00, 0x00, 0x0E, 0x00, 0x00, 0x70, 0x00, 0x00, 0x0E, 0x00, 0x00, 0xF0, 0x00, 0x00, 0x0F, 0x00, 0x00, 0xE0, 0x00, 0x00, 0x07, 0x00, 0x00, 0xE0, 0x00, 0x00, 0x07, 0x00, 0x00, 0xE0, 0x00, 0x00, 0x07, 0x00, 0x00, 0xE0, 0x00, 0x00, 0x07, 0x00, 0x00, 0xE0, 0x00, 0x00, 0x07, 0x00, 0x00, 0xE0, 0x00, 0x00, 0x07, 0x00, 0x00, 0xF0, 0x00, 0x00, 0x0F, 0x00, 0x00, 0x70, 0x00, 0x00, 0x0E, 0x00, 0x00, 0x70, 0x00, 0x00, 0x0E, 0x00, 0x00, 0x78, 0x00, 0x00, 0x1E, 0x00, 0x00, 0x3C, 0x38, 0x00, 0x3C, 0x00, 0x00, 0x3C, 0x38, 0x00, 0x3C, 0x00, 0x00, 0x1E, 0x3C, 0x00, 0x78, 0x00, 0x00, 0x0F, 0x9C, 0x01, 0xF0, 0x00, 0x00, 0x07, 0xFE, 0x03, 0xE0, 0x00, 0x00, 0x03, 0xFE, 0x07, 0xC0, 0x00, 0x00, 0x00, 0xFE, 0x03, 0x00, 0x00, 0x00, 0x00, 0x3F, 0x00, 0x00, 0x00, 0x00, 0x00, 0xFF, 0x00, 0x00, 0x00, 0x00, 0x01, 0xFC, 0x00, 0x00, 0x00, 0x00, 0x03, 0xF0, 0x00, 0x00, 0x00, 0x00, 0x01, 0xC0, 0x00, 0x00, 0x00, 0x00, 0x00, 0x00, 0x00, 0x00, 0x00, 0x00, 0x00, 0x00, 0x00, 0x00, 0x00, 0x00, 0x00, 0x00, 0x00, 0x00, 0x00, 0x00, 0x00, 0x00, 0x00, 0x00, 0x00, 0x00, 0x00, 0x00, 0x00, 0x00, 0x00};
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

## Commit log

2022-04-12 First Version of the LED Cubic Console
    With animation effects added (six in total); and a 3D snake game!
    Still to be debugged but the game is very playable
    The user controls the snake using two joysticks -- constant pulling
    The cube is rendered every 300us
    Refresh rate of the game can be easily changed and the default is set as 0.4s per frame.
2022-04-14 LED Snake Game Version2
2022-04-14 LED Pong Game Version1
2022-04-14 Circuit Designs
    [LED_cube.kicad_pcb, LED_cube.sch]
